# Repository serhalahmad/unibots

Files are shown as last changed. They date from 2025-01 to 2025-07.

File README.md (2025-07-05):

# Unibots

# How to Run WeBots Simulation in 5 Minutes
## Setup Conda Environment
- Important: pupil-apriltags works best on Python 3.10
1) git clone git@github.com:serhalahmad/unibots.git
2) cd unibots
3) conda create -n unibots-env python=3.10 -y
4) conda activate unibots-env
    - if 'conda init' before 'conda activate' error
    - Just type:
        - 'source ~/anaconda3/etc/profile.d/conda.sh' 
        - 'conda activate base'
        - 'conda activate unibots-env'
5) pip install -r requirements.txt
6) cd src\simulation\webots-files\main-env\controllers\controller_simulation
7) python controller_simulation.py (to check if no import errors occur)
8) Simulation:
    a. Tools -> Preferences -> Python command: Enter the path to the conda env's python.exe (e.g. C:\Users\Karl\anaconda3\envs\unibots-env\python.exe)
9) Hit "Play" in WeBots

## Simulation Image Previe
### Digital Twin Competition Arena
Simulation-Preview
### Object Tracking And Chasing Balls
Object-Tracking
### April Tag Detection to Return Home
April-Tag-Detection

## Real Robot Preview
### Our 3D-printed Robot
Robot-Image
### Object Tracking And Chasing Balls
Object-Tracking
### April Tag Detection to Return Home
April-Tag-Detection

## Our Team
Team-Image

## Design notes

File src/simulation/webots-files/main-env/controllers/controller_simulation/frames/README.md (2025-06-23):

This folder is to capture raw frames for data collection to then annotate them and train ai models

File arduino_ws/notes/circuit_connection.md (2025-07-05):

# DC Motor Connection
- Pin IP1 of L298N motor driver to digital pin 22 of Arduino Mega or digital pin 13 of Uno.
- Pin IP2 of L298N motor driver to digital pin 23 of Arduino Mega or digital pin 12 of Uno.
- Pin ENA of L298N motor driver to PWM pin 10 of Arduino Mega or digital pin 11 of Uno.
- Connect the motor to port J2 of the L298N motor driver. My convention is positive side closer to the heat sink.
- Connect the battery to J1 port of the L298N motor driver.
- TODO: NOTE that logically, I should have a common ground between arduino, motor driver, and the battery. My test worked without this. But for reliability, consider having a common ground and test it. 

# Servo Motor Connection
- Brown wire of the servo to a ground pin of Arduino Mega.
- Red wire of the servo to a 5V pin of Arduino Mega.
- Orange wire of the servo to PWM pin 9 of Arduino Mega.

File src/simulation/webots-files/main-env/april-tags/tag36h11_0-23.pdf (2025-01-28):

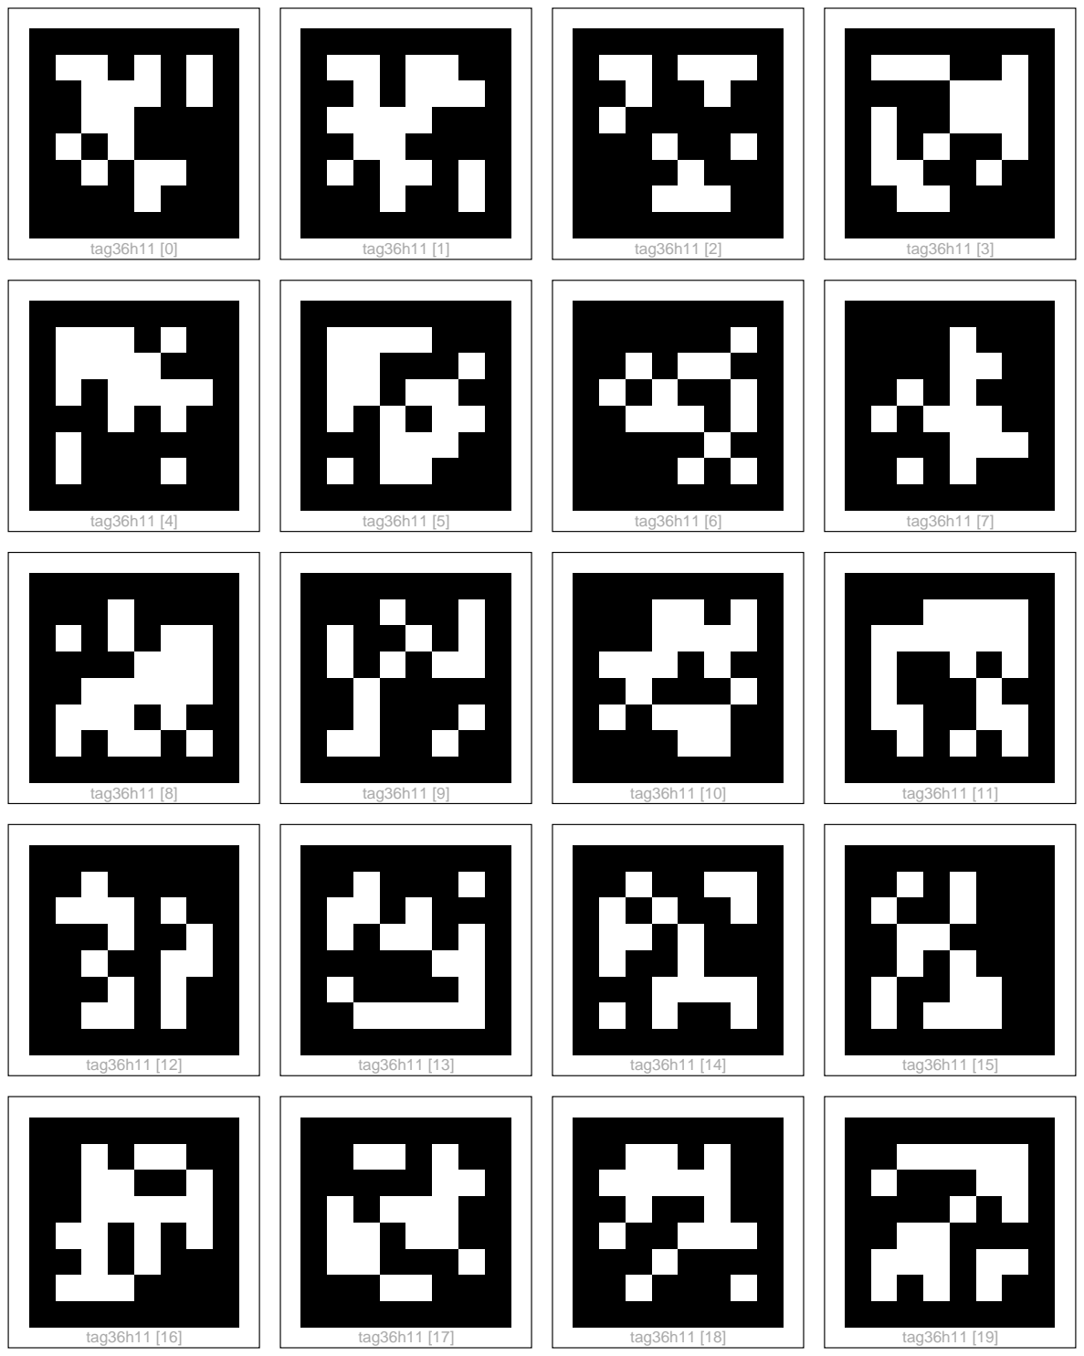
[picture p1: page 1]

tag36h11 [0] | tag36h11 [1] | tag36h11 [2] | tag36h11 [3]
tag36h11 [4] | tag36h11 [5] | tag36h11 [6] | tag36h11 [7]
tag36h11 [8] | tag36h11 [9] | tag36h11 [10] | tag36h11 [11]
tag36h11 [12] | tag36h11 [13] | tag36h11 [14] | tag36h11 [15]
tag36h11 [16] | tag36h11 [17] | tag36h11 [18] | tag36h11 [19]

tag36h11 [20] | tag36h11 [21] | tag36h11 [22] | tag36h11 [23]

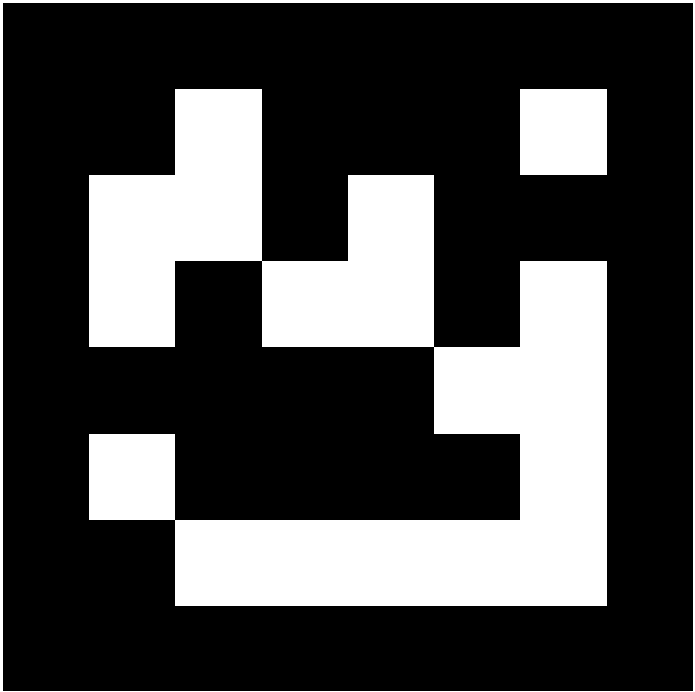
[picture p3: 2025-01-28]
src/simulation/webots-files/main-env/april-tags/tag-13.png

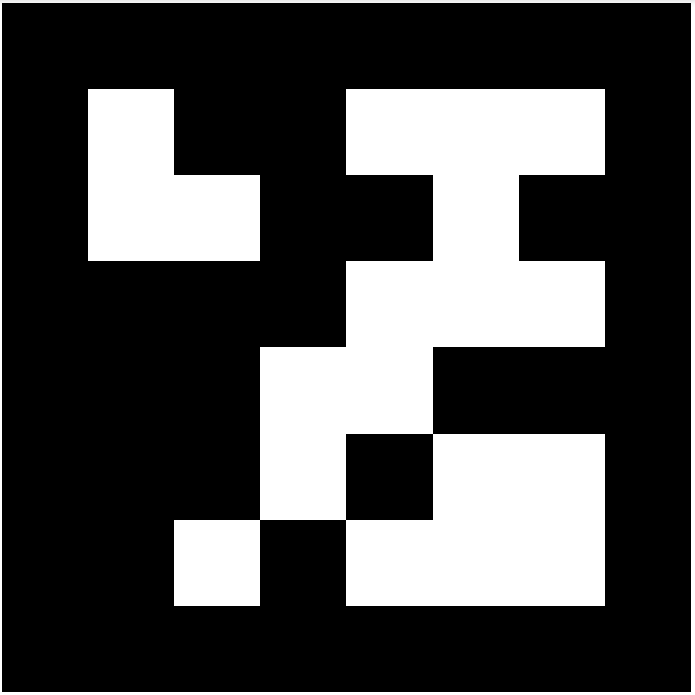
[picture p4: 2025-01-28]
src/simulation/webots-files/main-env/april-tags/tag-23.png

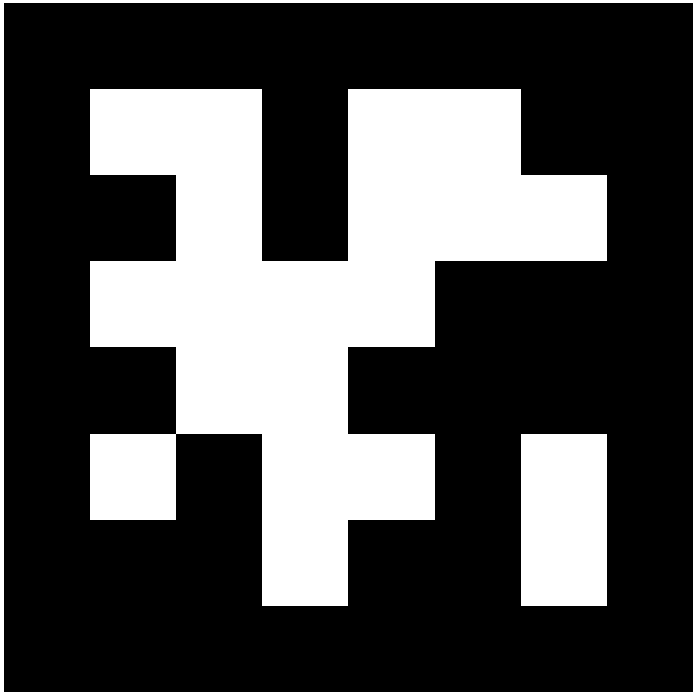
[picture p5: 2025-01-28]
src/simulation/webots-files/main-env/april-tags/tag-1.png

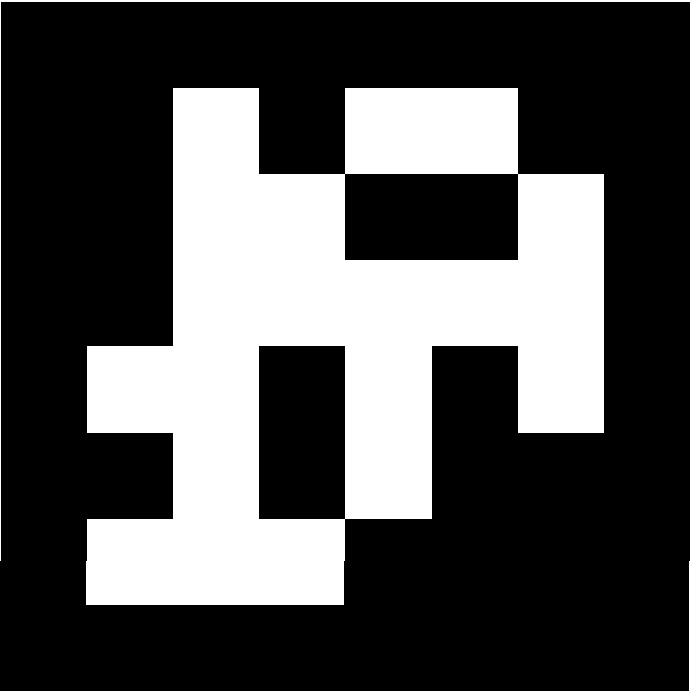
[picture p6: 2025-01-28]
src/simulation/webots-files/main-env/april-tags/tag-16.png

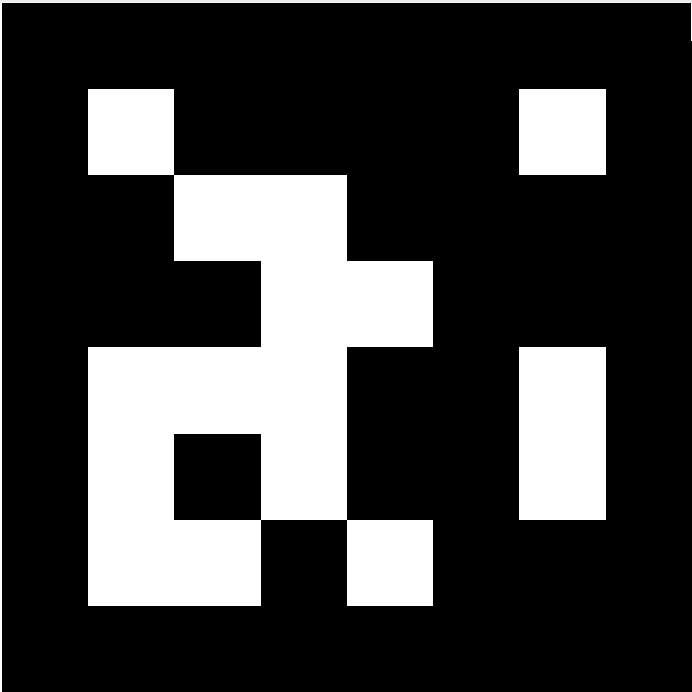
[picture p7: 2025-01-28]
src/simulation/webots-files/main-env/april-tags/tag-21.png

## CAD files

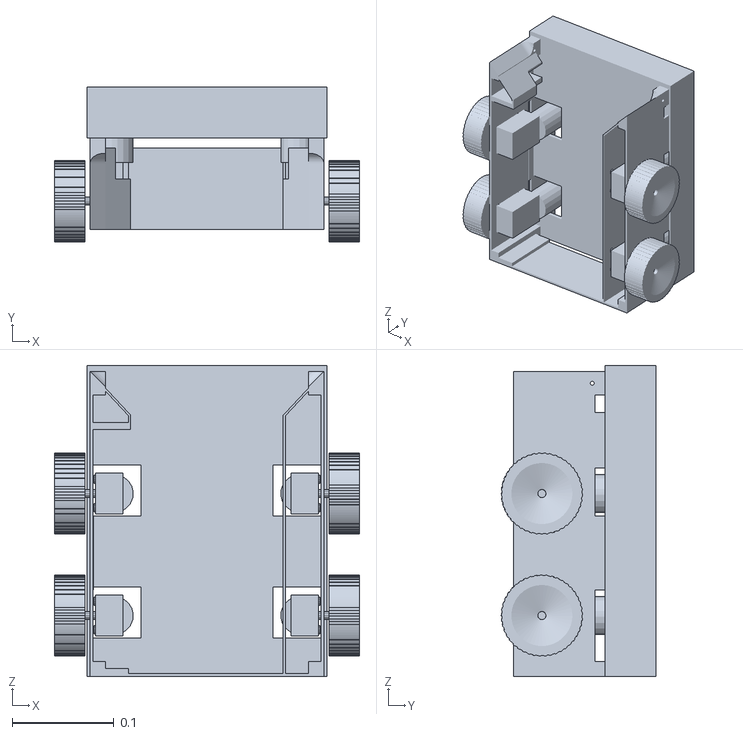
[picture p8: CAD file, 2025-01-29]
cad-files/motor/worm-gear-motor-high-torque-12v-dc-motor-1.snapshot.1/17_1_25 assembly.stl
0.3 x 0.152 x 0.306

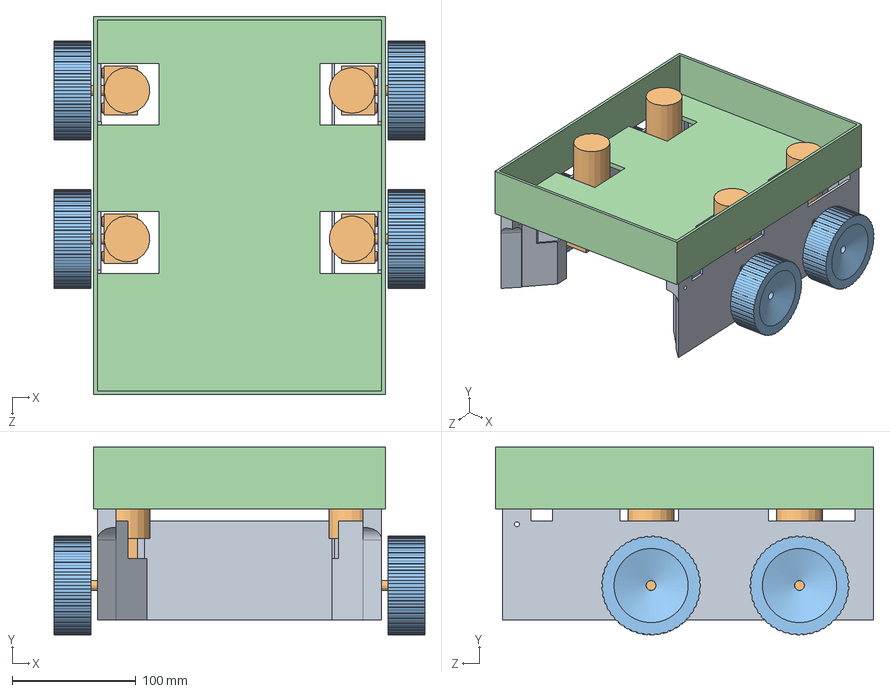
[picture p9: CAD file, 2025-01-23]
cad-files/17_1_25 assembly.SLDASM
300.0 x 152.0 x 306.0 mm
chassis
Worm Gear Motor x 4
tire x 4
17_1_25 layer1cover

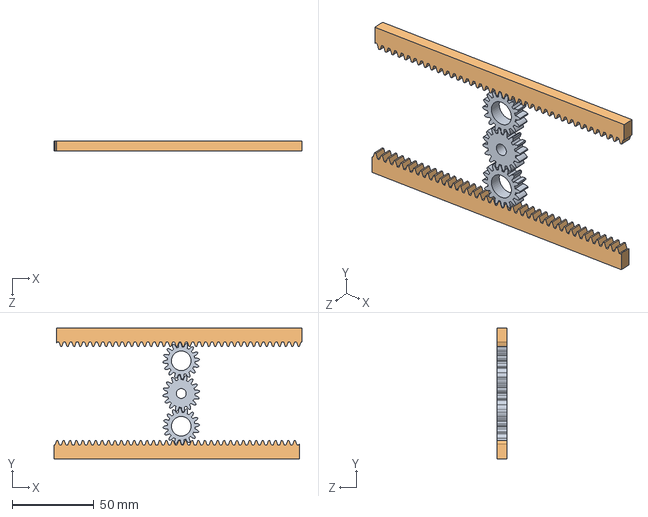
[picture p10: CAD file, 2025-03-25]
cad-files/unibots chassis/rugbymech.SLDASM
151.7 x 80.0 x 6.00 mm
spur gear_am x 3
rack spur rectangular_am x 2

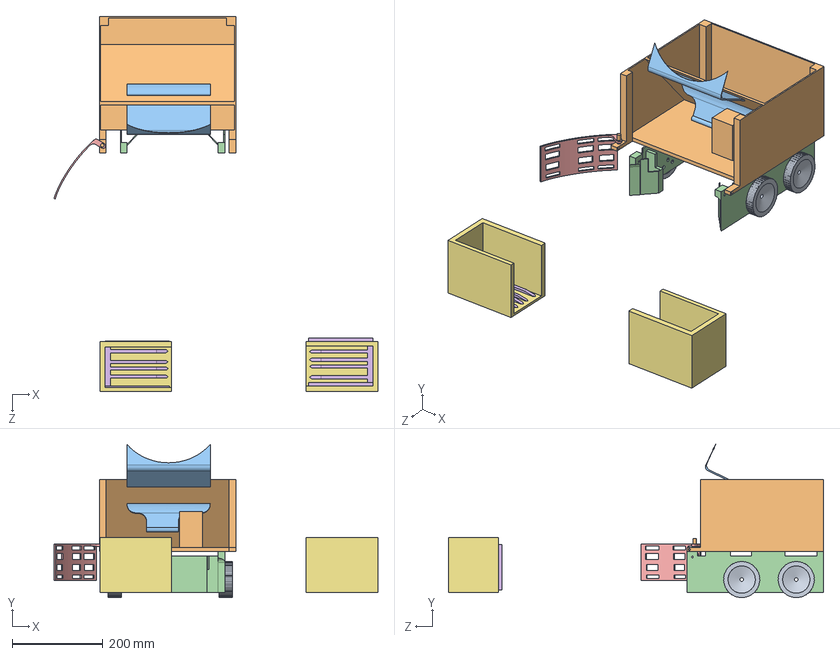
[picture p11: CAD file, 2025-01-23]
cad-files/unibots v1/trial assembly.SLDASM
712.2 x 337.4 x 824.7 mm
tire x 4
layer1cover
trialdoorv2
chassis
push door
testclamp x 2
testclamp2 x 2

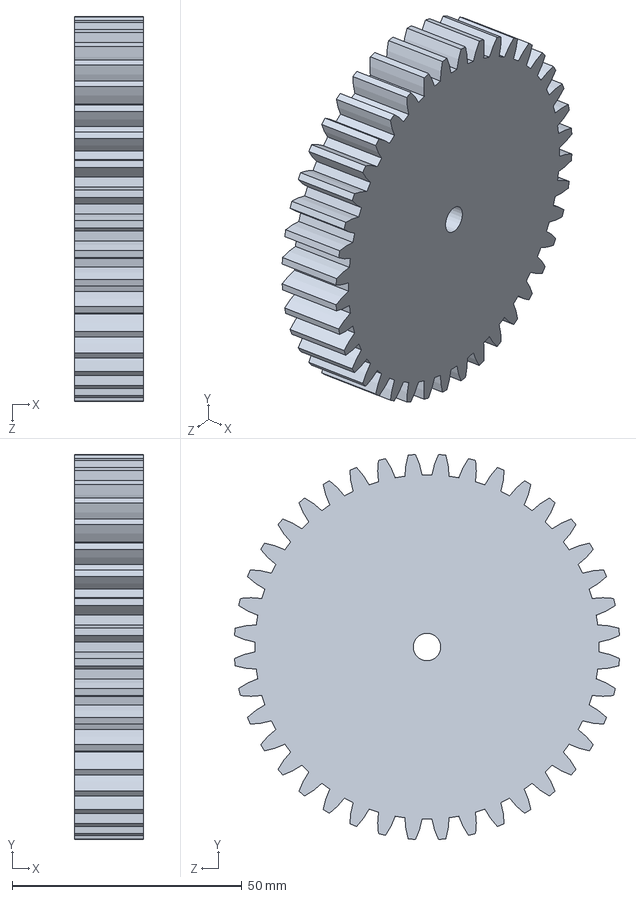
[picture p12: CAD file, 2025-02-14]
cad-files/gearbox test/bearing gear.SLDPRT.SLDASM
15.0 x 83.9 x 83.9 mm

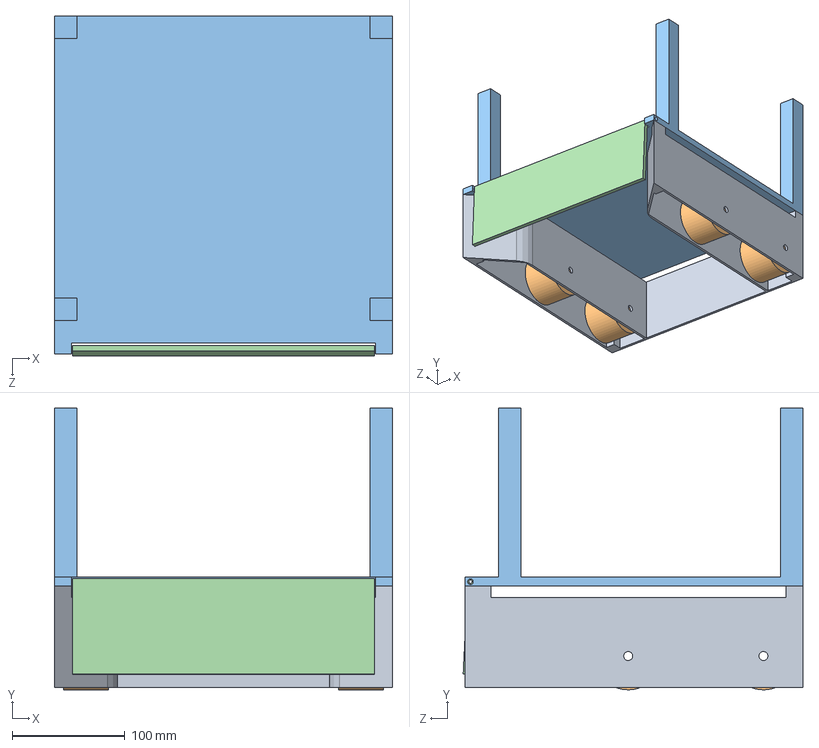
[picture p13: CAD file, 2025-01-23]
cad-files/trial assembly.SLDASM
300.0 x 250.0 x 301.5 mm
chassis
tire x 4
layer1cover
door

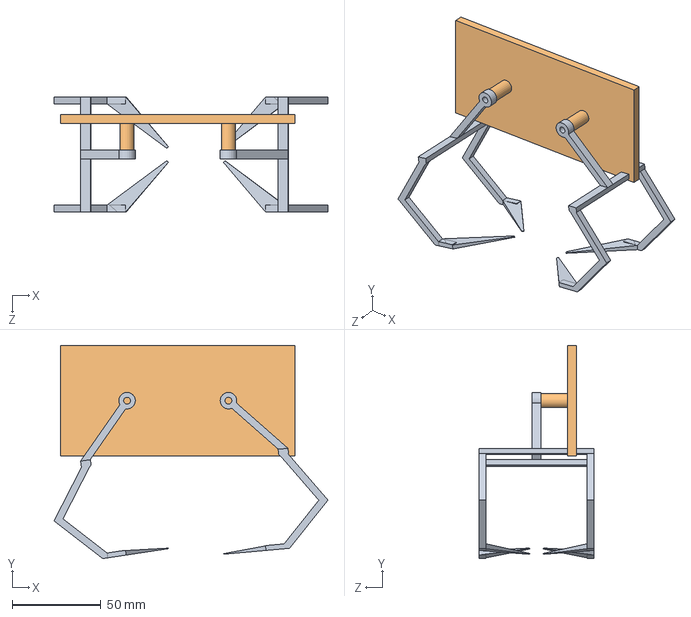
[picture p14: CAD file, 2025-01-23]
cad-files/17_1_25rugbymechtrial.SLDASM
154.7 x 120.4 x 65.0 mm
17_1_25 rugby x 2
plate

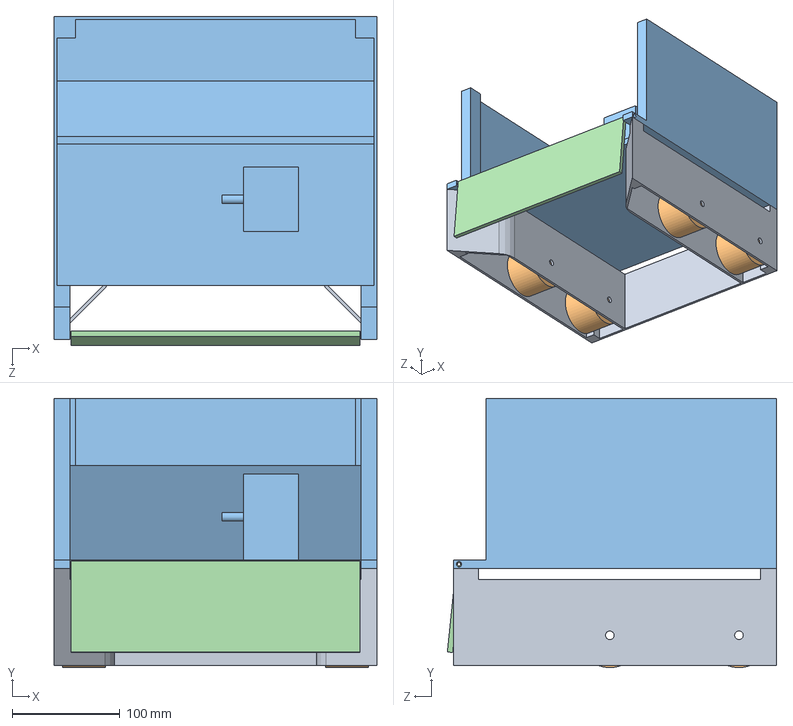
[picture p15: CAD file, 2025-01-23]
cad-files/Assem1.SLDASM
300.0 x 250.0 x 305.9 mm
chassis
tire x 4
layer1cover
door

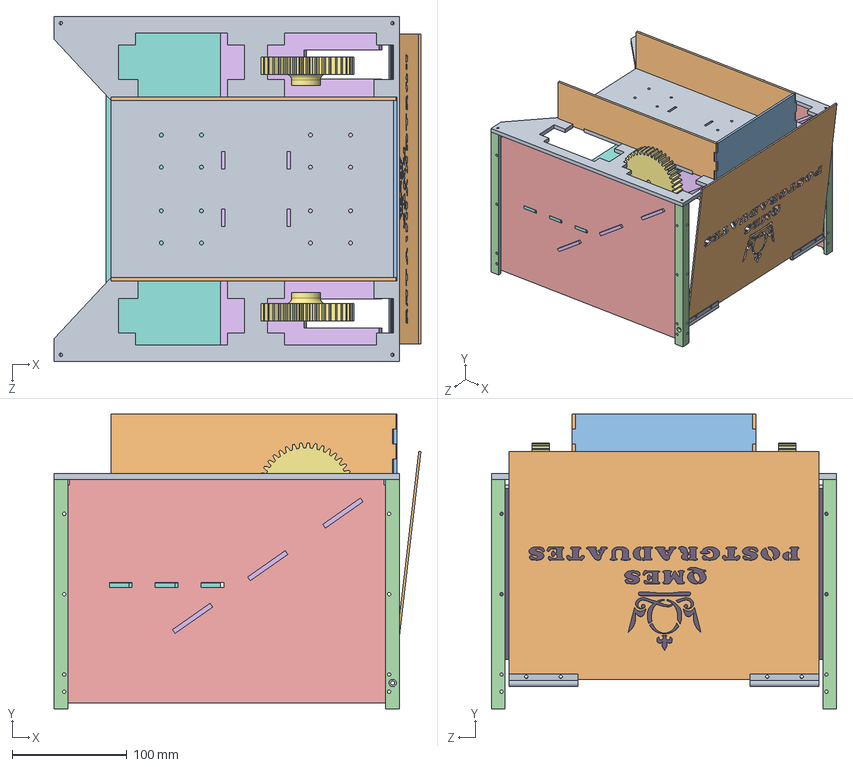
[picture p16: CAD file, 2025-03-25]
cad-files/unibots chassis/top layer new assembly.SLDASM
319.8 x 257.0 x 301.0 mm
layer1plate
pingpong-leftrightwall x 2
pingpong-bacjwall
beam.STL x 4
left-right wall x 2
diagonalwall1
motor gear x 2
flatwall
trapdoor beam x 2
trapdoorwall

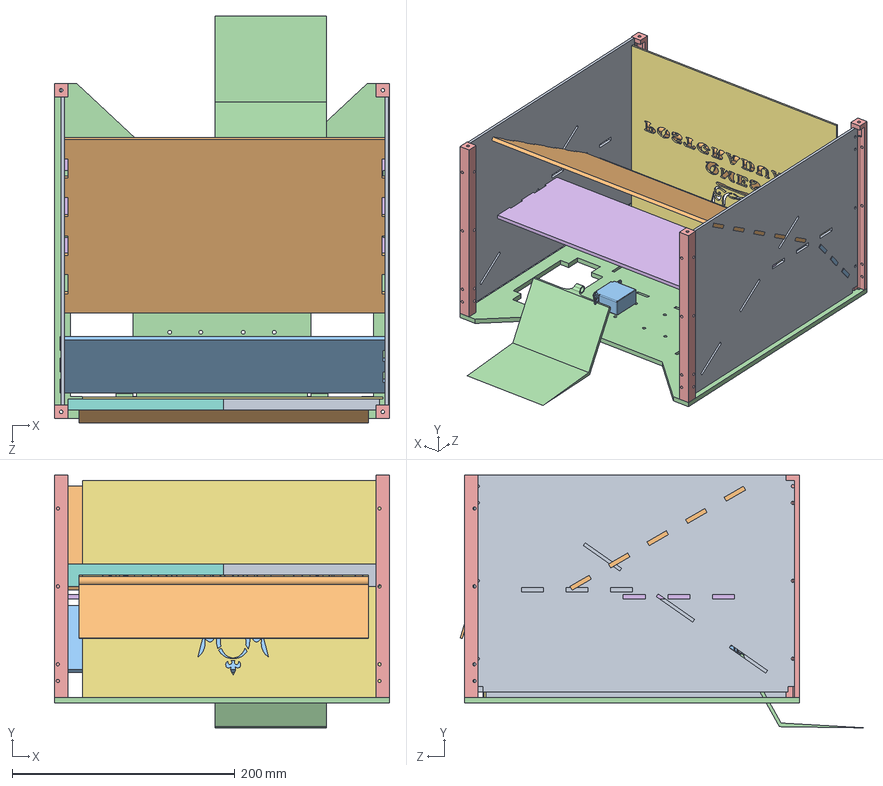
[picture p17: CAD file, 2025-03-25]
cad-files/unibots chassis/toplayer.SLDASM
301.0 x 227.2 x 365.4 mm
left-right wall x 2
rugbywall1
diagonallwall2
layer1plate
beam.STL x 4
flatwall
trapdoorwall
trapmechpart1
trapmechpart2
trapmechpart3
servo Hitec HS-225 MG
rugbymech2

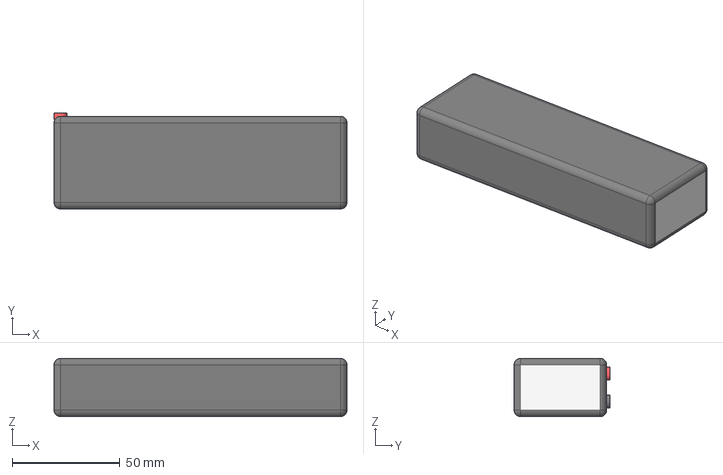
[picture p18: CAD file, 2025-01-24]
cad-files/battery/gens-ace-b-50c-5000-3s1p-bashing-5000mah-11-1v-3s-lipo-battery-60c-1.snapshot.2/Bashing_3S1P_11.1V_5000mAH_60c.stp
136.0 x 44.5 x 27.0 mm

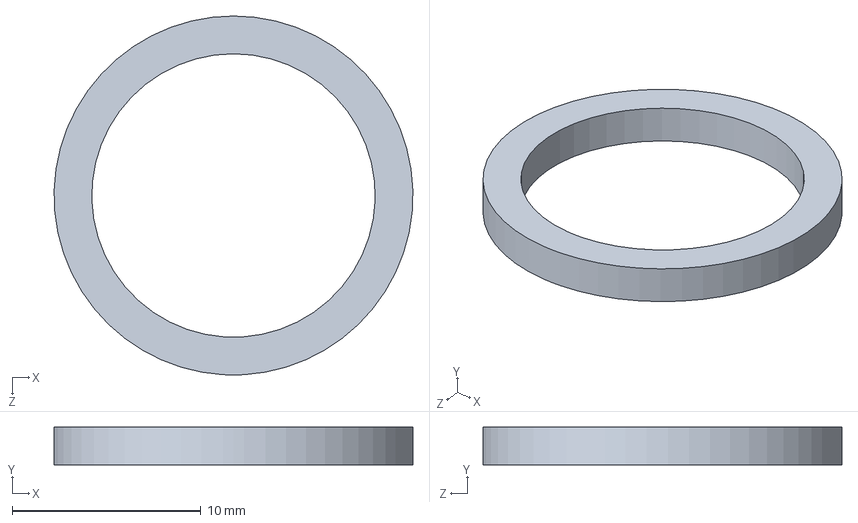
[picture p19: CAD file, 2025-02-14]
cad-files/gearbox test/bearing test.SLDPRT
19.0 x 2.00 x 19.0 mm

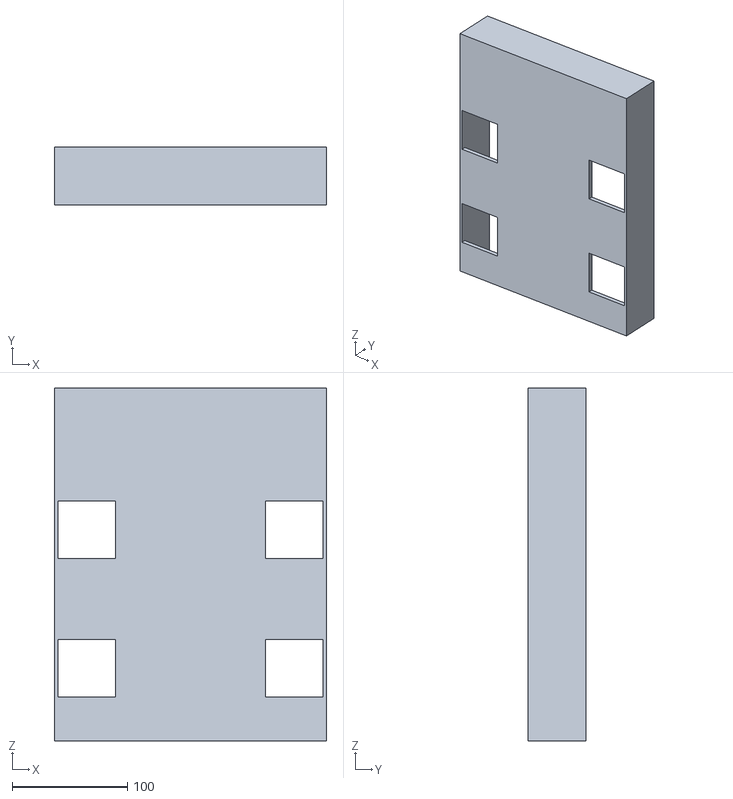
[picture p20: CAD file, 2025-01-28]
cad-files/New folder/17_1_25 layer1cover.STL
236.0 x 50.0 x 306.0

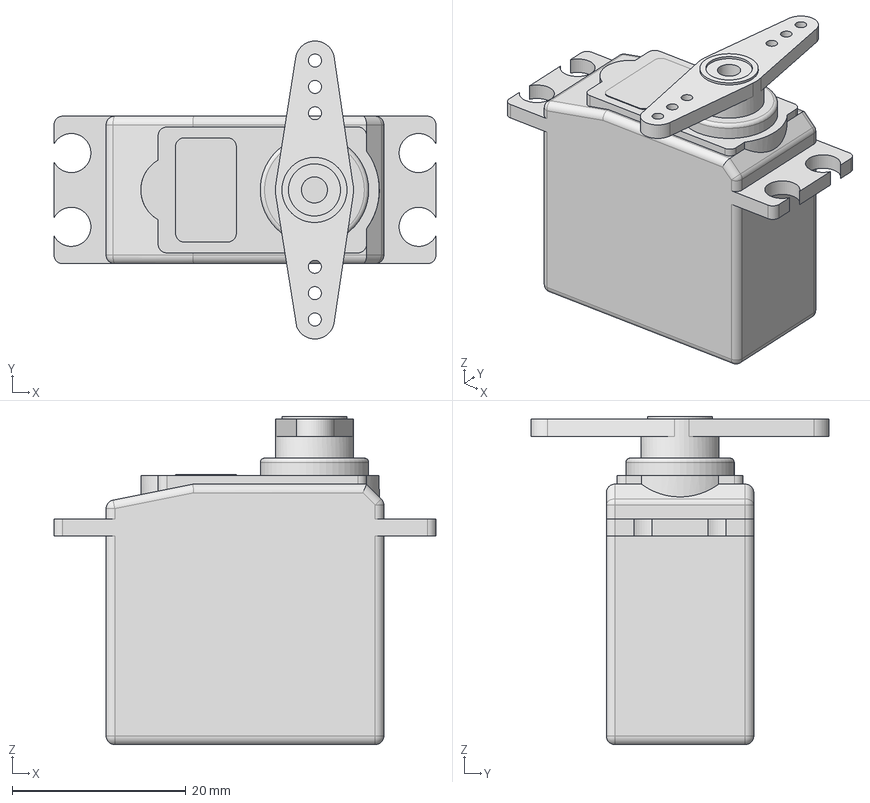
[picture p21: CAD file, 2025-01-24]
cad-files/servo/hitec-hs-225mg-1.snapshot.6/HS-225MG.step
44.0 x 34.3 x 37.8 mm

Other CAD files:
cad-files/servo/mg-996r-servo-motor-1.snapshot.23/Parts/MG996R Motor.SLDPRT
cad-files/tire.SLDPRT
cad-files/unibots chassis/beam.STL.SLDPRT
cad-files/unibots chassis/dxf files/componentsfloor.DXF
cad-files/17_1_25 assembly.stl
cad-files/17_1_25 layer1cover.SLDPRT
cad-files/17_1_25 layer1cover.stl
cad-files/17_1_25 rugby.SLDPRT
cad-files/17_1_25 rugby.stl
cad-files/17_1_25rugbymechtrial.stl
cad-files/New folder/Worm Gear Motor.STL
cad-files/New folder/chassis.STL
cad-files/New folder/tire.STL
cad-files/archive/17_1_25 assembly.stl
cad-files/archive/17_1_25 layer1cover.SLDPRT
cad-files/archive/17_1_25 layer1cover.stl
cad-files/archive/17_1_25 rugby.SLDPRT
cad-files/archive/17_1_25 rugby.stl
cad-files/archive/17_1_25rugbymechtrial.stl
cad-files/archive/New folder/Worm Gear Motor.STL
cad-files/archive/New folder/chassis.STL
cad-files/archive/New folder/tire.STL
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

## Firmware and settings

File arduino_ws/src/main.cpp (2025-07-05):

#include <Arduino.h>
#include <unibots_servo.hpp>
#include <unibots_dc_motor.hpp>

#define SERVO_MODE 0
#define DC_MOTOR_MODE 1
#define SERIAL_COM_MODE 2

// All motor names are when looking at the top of the robot and it is upward
// Also, the control pins are in a way that they are consecutively alligned with the motor pins
#define SERVO_PIN 6
#define DC_MOTOR_FR_PWM_PIN 10
#define DC_MOTOR_FL_PWM_PIN 9
#define DC_MOTOR_BR_PWM_PIN 10
#define DC_MOTOR_BL_PWM_PIN 9

#define DC_MOTOR_FR_CW_PIN 13
#define DC_MOTOR_FL_CW_PIN 12
#define DC_MOTOR_BR_CW_PIN 13
#define DC_MOTOR_BL_CW_PIN 12

#define DC_MOTOR_FR_CCW_PIN 8
#define DC_MOTOR_FL_CCW_PIN 7
#define DC_MOTOR_BR_CCW_PIN 8
#define DC_MOTOR_BL_CCW_PIN 7

UnibotsServo backServo(SERVO_PIN, 90);                                                    // servo for the back of the rugby storage
UnibotsDCMotor dc_motor_fr(DC_MOTOR_FR_PWM_PIN, DC_MOTOR_FR_CW_PIN, DC_MOTOR_FR_CCW_PIN); // Front-right motor
UnibotsDCMotor dc_motor_fl(DC_MOTOR_FL_PWM_PIN, DC_MOTOR_FL_CW_PIN, DC_MOTOR_FL_CCW_PIN); // Front-left motor
UnibotsDCMotor dc_motor_br(DC_MOTOR_BR_PWM_PIN, DC_MOTOR_BR_CW_PIN, DC_MOTOR_BR_CCW_PIN); // Back-right motor
UnibotsDCMotor dc_motor_bl(DC_MOTOR_BL_PWM_PIN, DC_MOTOR_BL_CW_PIN, DC_MOTOR_BL_CCW_PIN); // Back-left motor

int test_mode = SERIAL_COM_MODE;

void setup()
{
  Serial.begin(115200);
  switch (test_mode)
  {
  case SERVO_MODE:
    // Serial.begin(9600);
    backServo.attach();
    backServo.set_angle(90);
    break;
  case DC_MOTOR_MODE:
    // Serial.begin(115200);
    dc_motor_fr.begin();
    dc_motor_fl.begin();
    dc_motor_br.begin();
    dc_motor_bl.begin();
    break;
  case SERIAL_COM_MODE:
    // Serial.begin(115200);
    dc_motor_fr.begin();
    dc_motor_fl.begin();
    dc_motor_br.begin();
    dc_motor_bl.begin();
    break;
  default:
    break;
  }
}

void loop()
{
  // dc_motor_br.set_speed(75);
  // TODO: Back and front are mixed up
  switch (test_mode)
  {
  case SERVO_MODE:
    Serial.println("Testing Servo...");
    // backServo.set_angle(270); // catch
    // delay(1000);
    backServo.set_angle(-90); // release
    delay(1000);
    // backServo.set_angle(0);
    // delay(1000);
    break;
  case DC_MOTOR_MODE:
    // String received = "setVelocity 40 75";
    // int firstSpace = received.indexOf(' ');                                   // Find first space
    // int secondSpace = received.indexOf(' ', firstSpace + 1);                  // Find first space
    // int left_speed = received.substring(firstSpace + 1, secondSpace).toInt(); // Extract left speed
    // int right_speed = received.substring(secondSpace + 1).toInt();            // Extract right speed
    // dc_motor_fl.set_speed(left_speed);
    // dc_motor_bl.set_speed(left_speed);
    // dc_motor_fr.set_speed(right_speed);
    // dc_motor_br.set_speed(right_speed);
    //

    // NOTE: For some reason, we have to comment this out to test serial mode
    // int right_speed = -100;
    // int left_speed = 100;
    // dc_motor_fr.set_speed(right_speed);
    // dc_motor_fl.set_speed(left_speed);
    // dc_motor_br.set_speed(right_speed);
    // dc_motor_bl.set_speed(left_speed);
    // delay(2000);
    // dc_motor_fr.stop();
    // dc_motor_fl.stop();
    // dc_motor_br.stop();
    // dc_motor_bl.stop();
    // delay(1000);
    // break;
  case SERIAL_COM_MODE:
    if (Serial.available())
    {
      String received = Serial.readStringUntil('\n');
      if (received.startsWith("setVelocity"))
      {
        int firstSpace = received.indexOf(' ');                                   // Find first space
        int secondSpace = received.indexOf(' ', firstSpace + 1);                  // Find first space
        int left_speed = received.substring(firstSpace + 1, secondSpace).toInt(); // Extract left speed
        int right_speed = received.substring(secondSpace + 1).toInt();            // Extract right speed
        dc_motor_fl.set_speed(left_speed);
        dc_motor_bl.set_speed(left_speed);
        dc_motor_fr.set_speed(right_speed);
        dc_motor_br.set_speed(right_speed);
      }
      else if (received.startsWith("stop"))
      {
        dc_motor_fr.stop();
        dc_motor_fl.stop();
        dc_motor_br.stop();
        dc_motor_bl.stop();
      }
    }
    break;
  default:
    break;
  }
}

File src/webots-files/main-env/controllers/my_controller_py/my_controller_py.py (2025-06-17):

from controller import Robot
import numpy as np
from PIL import Image
from ultralytics import YOLO
import sys
import time
import cv2
from pupil_apriltags import Detector
import math
import os

current_dir = os.path.dirname(__file__)
relative_path = os.path.join(current_dir, '..', '..', 'weights', 'best.pt')
MODEL_PATH = os.path.abspath(relative_path)

################
### SETTINGS ###
################

# MODEL_PATH = r"yolo11s.pt" # Use standard model instead    
CONFIDENCE_THRESHOLD = 0.15
DETECTION_FRAME_INTERVAL = 25 # controls how many frames are skipped between apriltag / ball detection is performed
CAMERA_NAME = "camera"
DISTANCE_THRESHOLD = 50 # 300.0
HOME_IDS = [23, 0]
FORWARD_SPEED = 6.0  # Adjust this value as needed
ROTATION_SPEED = 4.0
MAX_MOTOR_SPEED = 6.28 # WeBots speed limit:= 6.28 rad/s
ANGLE_GAIN = 3
TURN_RATIO = 0.7
COMPETITION_START_TIME = 3 # seconds
GO_HOME_TIMER = 10 # seconds

### CAMERA PARAMETERS ###
FX = 1600 # focal length along x-axis
FY = 1600 # focal length along y-axis
TAG_SIDE_METERS = 0.1 # example: 10cm wide tags

# ROBOT STATES
COMPETITION = True
CHASE_BALL = True
RETURN_HOME = False

# INDEPENDENT STATES
COLLECT_DATA = False # save frames to disk, to create training data
COLLECT_INFERENCE_DATA = False # save inference data to disk, to check out inference results

TAG_POSITIONS = {
    0:  (150, 2000),
    1:  (450, 2000),
    2:  (750, 2000),
    3:  (1250, 2000),
    4:  (1550, 2000),
    5:  (1850, 2000),
    6:  (2000, 1850),
    7:  (2000, 1550),
    8:  (2000, 1250),
    9:  (2000, 750),
    10: (2000, 450),
    11: (2000, 150),
    12: (1850, 0),
    13: (1550, 0),
    14: (1250, 0),
    15: (750, 0),
    16: (450, 0),
    17: (150, 0),
    18: (0, 150),
    19: (0, 450),
    20: (0, 750),
    21: (0, 1250),
    22: (0, 1550),
    23: (0, 1850),
}


def load_model(model_pth=MODEL_PATH):
    ''' Initialize YOLOv11 Model on CPU '''
    model = None
    try:
        print("Loading YOLOv11 model on CPU...")
        model = YOLO(model_pth)
        model.to("cpu")
        print("YOLOv11 model loaded successfully on CPU.")
    except Exception as e:
        print(f"Error loading YOLOv11 model: {e}")
        sys.exit(1)
    return model


def init_environment(robot):
    ''' Initialize the robot variables '''
    timestep = int(robot.getBasicTimeStep())

    # Initialize the left and right motors
    left_motor = robot.getDevice("left wheel motor")
    right_motor = robot.getDevice("right wheel motor")

    # Change position to inf -> to set velocity control mode
    left_motor.setPosition(float("inf"))
    right_motor.setPosition(float("inf"))

    # Initialize the camera
    camera = robot.getDevice(CAMERA_NAME)
    camera.enable(timestep)
    
    return timestep, camera, left_motor, right_motor


def bytes_to_numpy(img_bytes, camera):
    """
    Converts image bytes from the camera to a writeable NumPy array.

    Args:
        img_bytes (bytes): Image data from the camera.
        camera (RobotCamera): The camera device.

    Returns:
        numpy.ndarray or None: RGB image as a NumPy array or None if conversion fails.
    """
    try:
        width = camera.getWidth()
        height = camera.getHeight()
        # Convert the raw image data to a NumPy array
        img_array = np.frombuffer(img_bytes, dtype=np.uint8).reshape((height, width, 4))
        # Convert RGBA to RGB by removing the alpha channel and make a copy to ensure writeability
        img_rgb = img_array[:, :, :3].copy()
        return img_rgb
    except Exception as e:
        print(f"Error converting bytes to NumPy array: {e}")
        return None


def ball_detection(img, camera, model):
    global COLLECT_INFERENCE_DATA
    global CONFIDENCE_THRESHOLD
    x_center_int = None
    try:
        # Get image dimensions
        width = camera.getWidth()
        height = camera.getHeight()

        # Convert the raw image data to a NumPy array
        img_array = np.frombuffer(img, dtype=np.uint8).reshape((height, width, 4))

        # Convert RGBA to RGB by removing the alpha channel
        img_rgb = img_array[:, :, :3]

        # Create a PIL Image from the NumPy array
        image = Image.fromarray(img_rgb)
        image_np = np.array(image)
        print("Model inference starting...")

        # Run the YOLOv11 model on the image
        results = model(image_np, conf=CONFIDENCE_THRESHOLD, save=COLLECT_INFERENCE_DATA)

        # Process and print detected objects
        result = results[0]  # Since there's only one image
        boxes = result.boxes  # Boxes object for bounding box outputs
        if boxes:
            for box in boxes:
                # Extract the bounding box coordinates (x1, y1, x2, y2)
                x1, y1, x2, y2 = box.xyxy[0]
                print(box.xyxy)
                # Calculate the center x position
                x_center = (x1 + x2) / 2

                # Convert to integer
                x_center_int = int(x_center.item())
        else:
            print("Image 0: []")

    except Exception as e:
        print(f"Error during image processing or detection: {e}")
    return x_center_int


def get_destination_coordinate(destination_ids):
    """
    Given two tag IDs that define a corner, return the (x,y) for 'home'.
    One simple approach is just to average the corner tags' coordinates.
    """
    if len(destination_ids) != 2:
        raise ValueError("destination_ids must have exactly two elements")
    tid1, tid2 = destination_ids
    (x1, y1) = TAG_POSITIONS[tid1]
    (x2, y2) = TAG_POSITIONS[tid2]
    # For a “corner,” often these two tags are close, so just take midpoint:    
    return ((x1 + x2)/2.0, (y1 + y2)/2.0)
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

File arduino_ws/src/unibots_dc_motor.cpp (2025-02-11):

#include "unibots_dc_motor.hpp"

UnibotsDCMotor::UnibotsDCMotor(int pwm_pin, int cw_pin, int ccw_pin) : _pwm_pin(pwm_pin), _cw_pin(cw_pin), _ccw_pin(ccw_pin), _speed(0) {}

void UnibotsDCMotor::begin()
{
    pinMode(_pwm_pin, OUTPUT);
    pinMode(_cw_pin, OUTPUT);
    pinMode(_ccw_pin, OUTPUT);
    stop(); // Ensure motor starts stopped
}

void UnibotsDCMotor::set_speed(int speed)
{
    _speed = constrain(speed, -255, 255); // Ensure valid range

    if (_speed > 0)
    {
        digitalWrite(_cw_pin, HIGH);
        digitalWrite(_ccw_pin, LOW);
    }
    else if (_speed < 0)
    {
        digitalWrite(_cw_pin, LOW);
        digitalWrite(_ccw_pin, HIGH);
    }
    else
    {
        stop(); // Stop if speed = 0
        return;
    }
    analogWrite(_pwm_pin, abs(_speed)); // Set PWM speed
}

void UnibotsDCMotor::stop()
{
    digitalWrite(_cw_pin, LOW);
    digitalWrite(_ccw_pin, LOW);
    analogWrite(_pwm_pin, 0);
}

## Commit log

2025-01-24 updated folder structure
    [17_1_25 assembly.SLDASM, 17_1_25 layer1cover.SLDPRT, 17_1_25 rugby.SLDPRT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]
2025-01-29 converted solidworks files to .stl
    [17_1_25 assembly.SLDASM, 17_1_25 assembly.stl, 17_1_25 layer1cover.stl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]
2025-01-30 Setup an arduino workspace
2025-01-31 Wrote a driver for the servo motors
2025-02-11 Created a drvier for the DC motors
2025-02-11 Fixed the namings in the servo driver and added a guide on how to connect the servo and DC motors.
    [main.cpp]
2025-03-17 Added other motors variables but NOT tested
2025-03-17 Implemented RPi-Arduino serial communication
2025-03-23 updated structure and added security
    [17_1_25 assembly.SLDASM, 17_1_25 assembly.stl, 17_1_25 layer1cover.SLDPRT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]
2025-03-23 added switching between robot states and rotation when no ball detected
2025-03-25 Camera code. Untested!
2025-03-26 added print statements to real controller
2025-03-27 added test-components scripts
    [results.csv]
2025-03-27 updated wheel motor scripts
2025-03-27 updated test_servo_motors to work with new servo motor scripts
2025-03-27 Test for motors and serial
2025-03-27 test different weight files on robot
    [model.ncnn.param]
2025-03-27 optimized object detection from 2.85 seconds down to 0.5 seconds
    [model.ncnn.param]
2025-03-28 added rugby balls to simulation and extract object detection class names
    [rugby-ball.obj]
2025-03-28 Fixed the motor directions following the latest circuit connection
    [main.cpp]
2025-03-28 fixed real world robot movement
    [real_controller_py.py]
2025-03-29 updated test servo motors script
2025-03-29 Implemented the feature of knowing if the detected color is facing the camera or aligning with it
2025-06-17 restructured unibots folders
    [rugby-ball.obj]
2025-06-23 fixed folder structure to recognize simulation controller
    [controller_simulation.py]
